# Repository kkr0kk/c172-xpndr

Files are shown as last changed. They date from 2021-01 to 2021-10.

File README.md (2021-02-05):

<H1>BENDIX king KT76C - flight sim transponder - for Cessna 172 - DIY</H1>
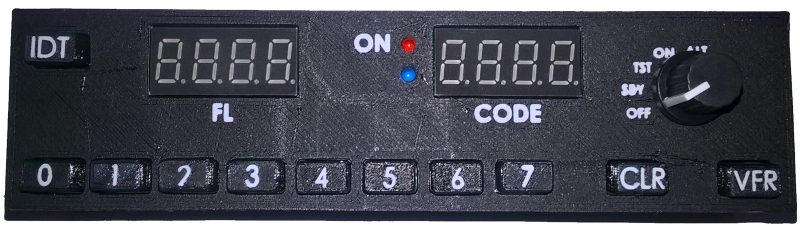
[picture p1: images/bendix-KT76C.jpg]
Bendix KT76C sim flight transponder

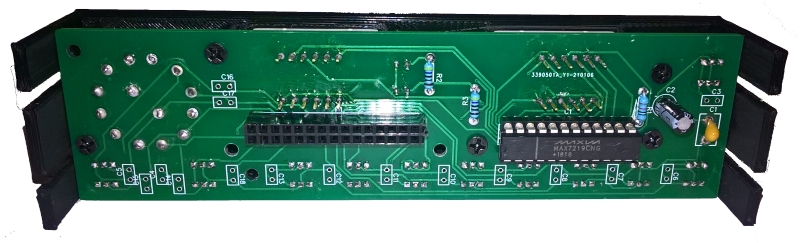
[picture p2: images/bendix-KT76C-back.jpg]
Bendix KT76C sim flight transponder

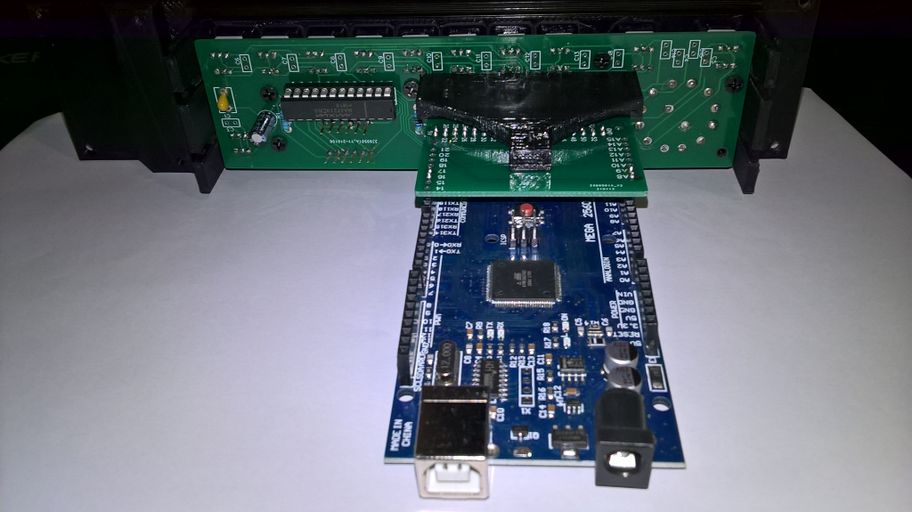
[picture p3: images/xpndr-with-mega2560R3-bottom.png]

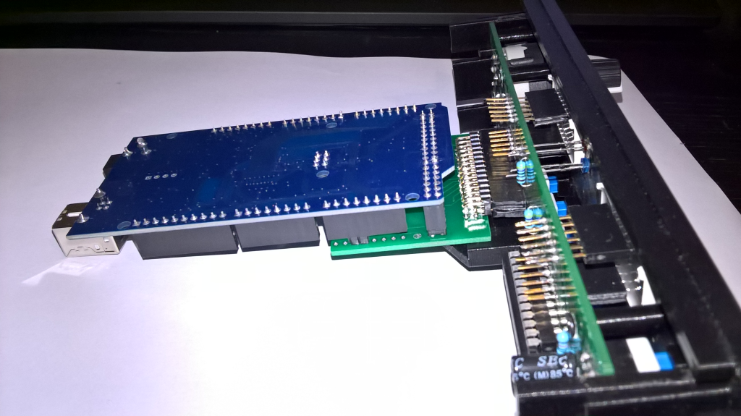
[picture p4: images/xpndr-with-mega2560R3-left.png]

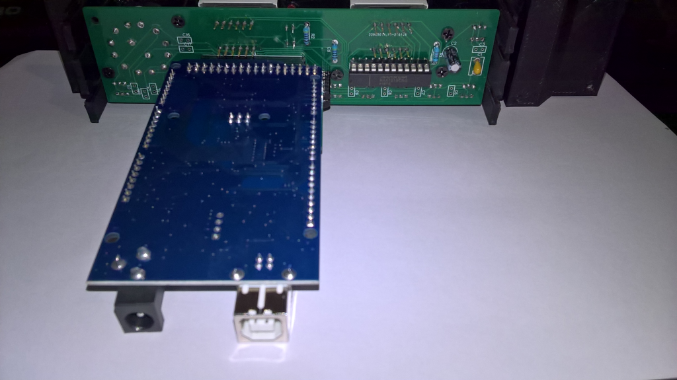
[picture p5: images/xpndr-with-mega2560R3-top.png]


Build your own transponder for simulation cockpit cessna 172.<BR />
Format for 6.25" stack<BR />
Electronics are design with EasyEDA.<BR />
3D parts are design with SolidWorks.<BR />
PCB are sold by JLCPCB, you can use directly Gerber files --> <a href='https://jlcpcb.com/'>JLCPCB</a><BR />
Only electronics, you can choose the microcontroller of your choice, the base design have addtionnal card for Mega2560R3.
For mine i use Mega2560R3 and Mobiflight on MSFS2020--> <a href='https://www.mobiflight.com/en/index.html'>MOBIFLIGHT</a><BR />
For others controllers you need to design the support for the card, or add wires to link them.
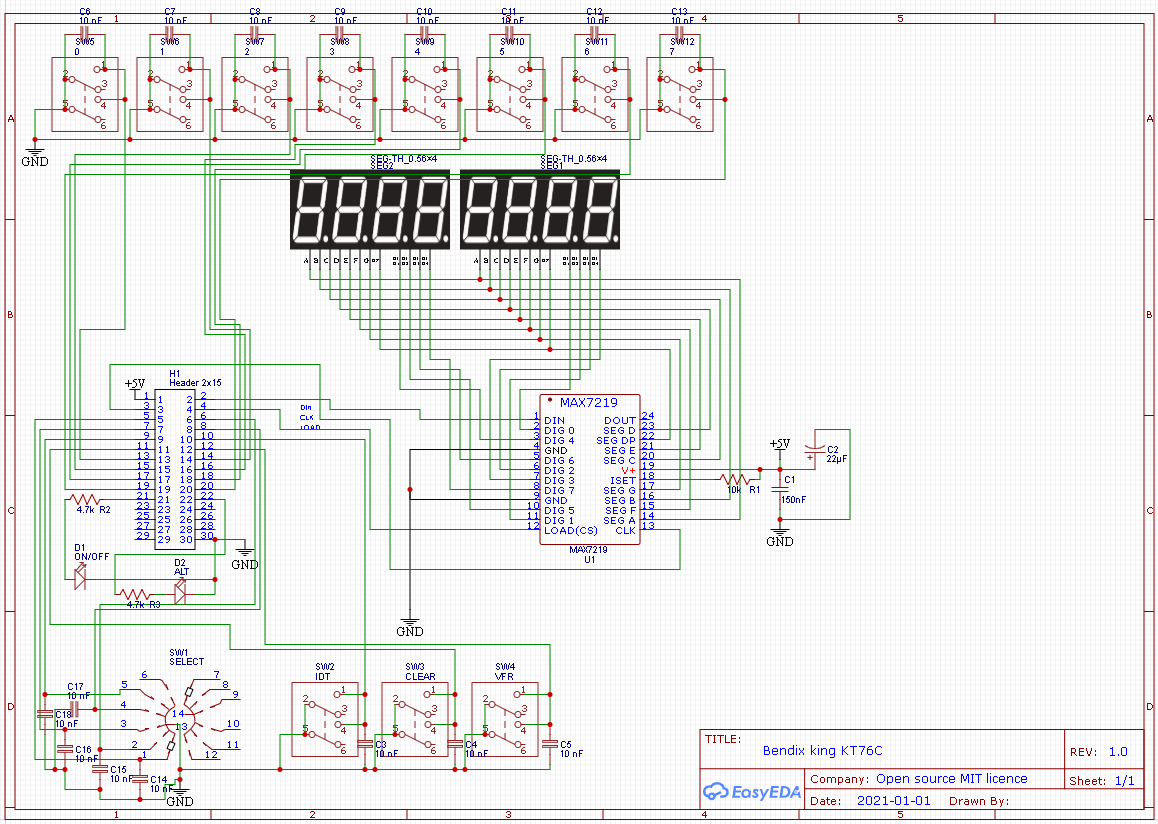
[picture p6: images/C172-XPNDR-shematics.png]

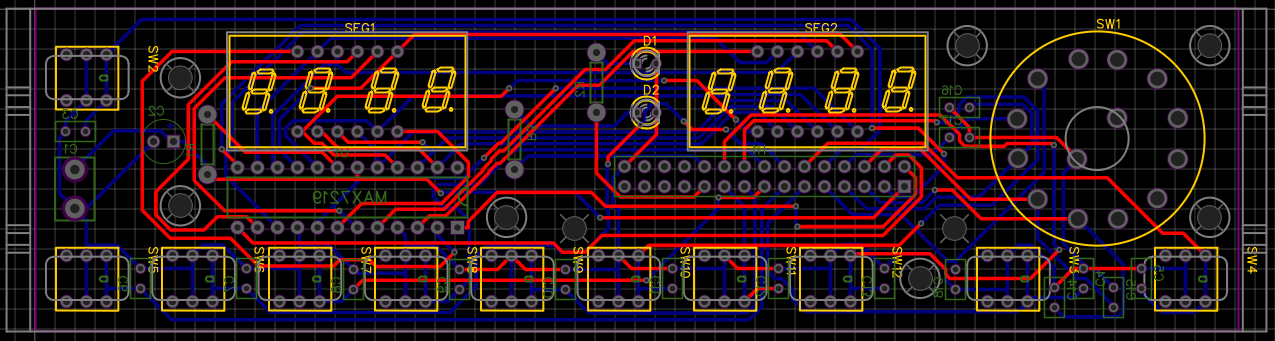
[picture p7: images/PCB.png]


Capacitor C3 to C18 are optionnals, they just do debounce for switch, but work fine wihtout on mobiflight.<BR/>

Parts list:

MAX7219 x1 --> <a href='https://fr.aliexpress.com/item/32874536319.html?spm=a2g0s.9042311.0.0.27426c37hpiJs6'>Aliexpress</a><BR />
Selector 2P6T x1 --> <a href='https://fr.aliexpress.com/item/32949497961.html?spm=a2g0s.9042311.0.0.338d6c379S0zX2'>Aliexpress</a><BR />
Screen 7 Seg 4 digits x2 --> <a href='https://fr.aliexpress.com/item/32673704841.html?spm=a2g0s.9042311.0.0.338d6c379S0zX2'>Aliexpress</a><BR />
Switch 8x8m x11 --> <a href='https://fr.aliexpress.com/item/32467872702.html?spm=a2g0s.9042311.0.0.338d6c379S0zX2'>Aliexpress</a><BR />
LED red 3mm x2 --> <a href='https://fr.aliexpress.com/item/4000968613440.html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,searchweb201602_,searchweb201603_'>Aliexpress</a><BR />
Capacitor 10nF x16--> <a href='https://fr.aliexpress.com/item/32971478818.html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,searchweb201602_,searchweb201603_'>Aliexpress</a>
<a href='https://fr.aliexpress.com/item/32896781515.html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,searchweb201602_,searchweb201603_'>Aliexpress</a><BR />
High Frequency Low ESR Aluminum Capacitor 22µF 50V x1 --> <a href='https://www.aliexpress.com/item/33030332216.html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,searchweb201602_,searchweb201603_'>Aliexpress</a><BR />
Capacitor 0.15µF x1 --> <a href='https://fr.aliexpress.com/item/32719073307.html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,searchweb201602_,searchweb201603_'>Aliexpress</a><BR />
Resistor 1/4W 10k&#x2126; x1<BR />
Resistor 1/4W 10k&#x2126; x2<BR />
Header male angle 2x15pin x1 --> <a href='https://fr.aliexpress.com/item/33043163402.html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,searchweb201602_,searchweb201603_'>Aliexpress</a><BR />
Header female 2x15pin x1<BR />
Header female 1x6pin x4 (for 7 segment) --> <a href='https://fr.aliexpress.com/item/4000106121057.html?spm=a2g0s.9042311.0.0.584d6c374vkTRE'>aliexpress</a><BR />

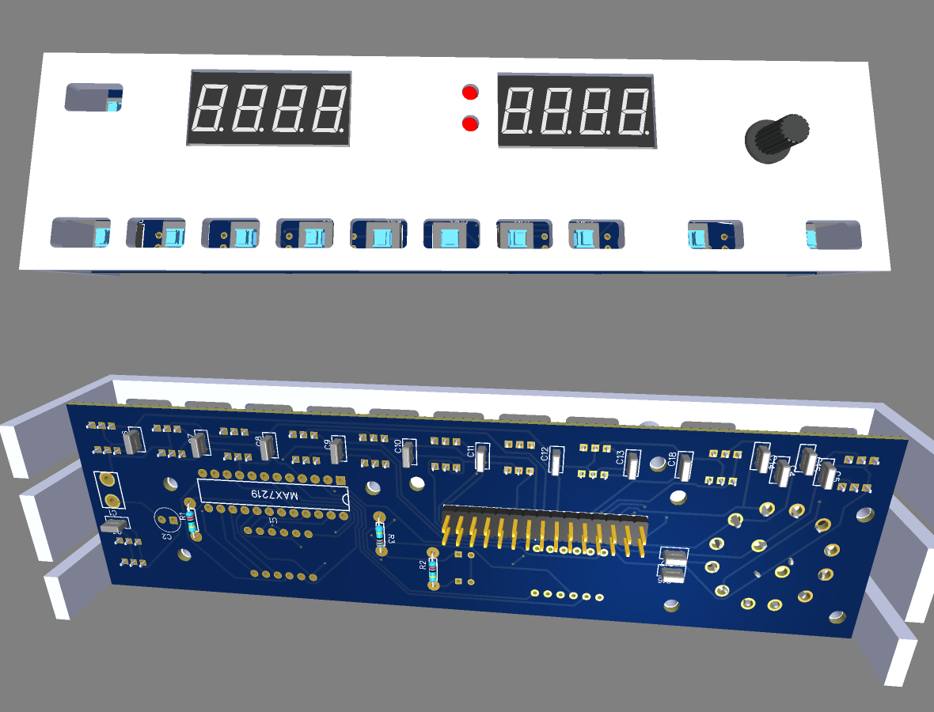
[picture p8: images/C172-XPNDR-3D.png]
<BR />
<table>
<tr>
	<th>PIN mega2560 R3</th><th>PIN Header H1</th><th>Device</th>
</tr>
<tr>
	<td>5V</td><td>1</td><td>--</td>
</tr><tr>
	<td>22</td><td>2</td><td>U1 - DIN (LCD)</td>
</tr><tr>
	<td>23</td><td>3</td><td>U1 - CLK (LCD)</td>
</tr><tr>
	<td>24</td><td>4</td><td>U1 - LOAD (LCD)</td>
</tr><tr>
	<td>25</td><td>5</td><td>SW1 - mode off</td>
</tr><tr>
	<td>26</td><td>6</td><td>SW1 - mode standby</td>
</tr><tr>
	<td>27</td><td>7</td><td>SW1 - mode test</td>
</tr><tr>
	<td>28</td><td>8</td><td>SW1 - mode on</td>
</tr><tr>
	<td>29</td><td>9</td><td>SW1 - mode alt</td>
</tr><tr>
	<td>30</td><td>10</td><td>SW2 - IDT</td>
</tr><tr>
	<td>31</td><td>11</td><td>SW3 - CLEAR</td>
</tr><tr>
	<td>32</td><td>12</td><td>SW4 - VFR</td>
</tr><tr>
	<td>33</td><td>13</td><td>SW5 - 0</td>
</tr><tr>
	<td>34</td><td>14</td><td>SW6 - 1</td>
</tr><tr>
	<td>35</td><td>15</td><td>SW6 - 2</td>
</tr><tr>
	<td>36</td><td>16</td><td>SW6 - 3</td>
</tr><tr>
	<td>37</td><td>17</td><td>SW6 - 4</td>
</tr><tr>
	<td>38</td><td>18</td><td>SW6 - 5</td>
</tr><tr>
	<td>39</td><td>19</td><td>SW6 - 6</td>
</tr><tr>
	<td>40</td><td>20</td><td>SW6 - 7</td>
</tr><tr>
	<td>41</td><td>21</td><td>LED D1 on/off</td>
</tr><tr>
	<td>42</td><td>22</td><td>LED D2 mode alt</td>
</tr><tr>
	<td>-</td><td>23</td><td>not use</td>
</tr><tr>
	<td>-</td><td>24</td><td>not use</td>
</tr><tr>
	<td>-</td><td>25</td><td>not use</td>
</tr><tr>
	<td>-</td><td>26</td><td>not use</td>
</tr><tr>
	<td>-</td><td>27</td><td>not use</td>
</tr><tr>
	<td>-</td><td>28</td><td>not use</td>
</tr><tr>
	<td>-</td><td>29</td><td>not use</td>
</tr><tr>
	<td>GND</td><td>30</td><td>GND</td>
</tr>
</table>
<H2>3D Printing</H2>
<H3>Materials</H3>
- HEAD : 0.2mm and 0.6mm<BR />
- PLA BLACK and PLA WHITE<BR />
<H3>How to print this with text</H3>
i use a rewrite plugin With CURA -> <a href='https://github.com/kkr0kk/c172-autopilot/blob/main/Gcode/pauseAtZ.py'>PauseAtZ</a><BR />
First you need to print just the text with head 0.2mm and white PLA (piece need to be rotate 180° text must be on the plate, keep your piece in center) -> <a href="https://github.com/kkr0kk/c172-xpndr/blob/main/STL%203Dprint%20files/chassis%20layer1.STL">STL file</a> or <a href="https://github.com/kkr0kk/c172-xpndr/blob/main/Gcode/chassis%20layer%201%20text%20head%200.2.gcode">GCODE file</a><BR />
When the text is print, Printer go pause, you can cancel the print.<BR />
Change the head by 0.6mm and load new PLA black (do enormous purge)<BR />
And go print the layer 2 -> <a href="https://github.com/kkr0kk/c172-xpndr/blob/main/STL%203Dprint%20files/chassis%20layer2.STL">STL file</a> or <a href="https://github.com/kkr0kk/c172-xpndr/blob/main/Gcode/chassis%20layer%202%20head%200.6.gcode">GCODE file</a><BR />
You can use cura profile -> <a href="https://github.com/kkr0kk/c172-xpndr/blob/main/Gcode/chassis%20text%20head%200.2%20layer%201.ini">Layer 1 profile with 0.2mm head</a> and <a href="https://github.com/kkr0kk/c172-xpndr/blob/main/Gcode/chassis%20layer%202%20head%200.6.gcode">layer 2 profile with 0.6mm head</a><BR />

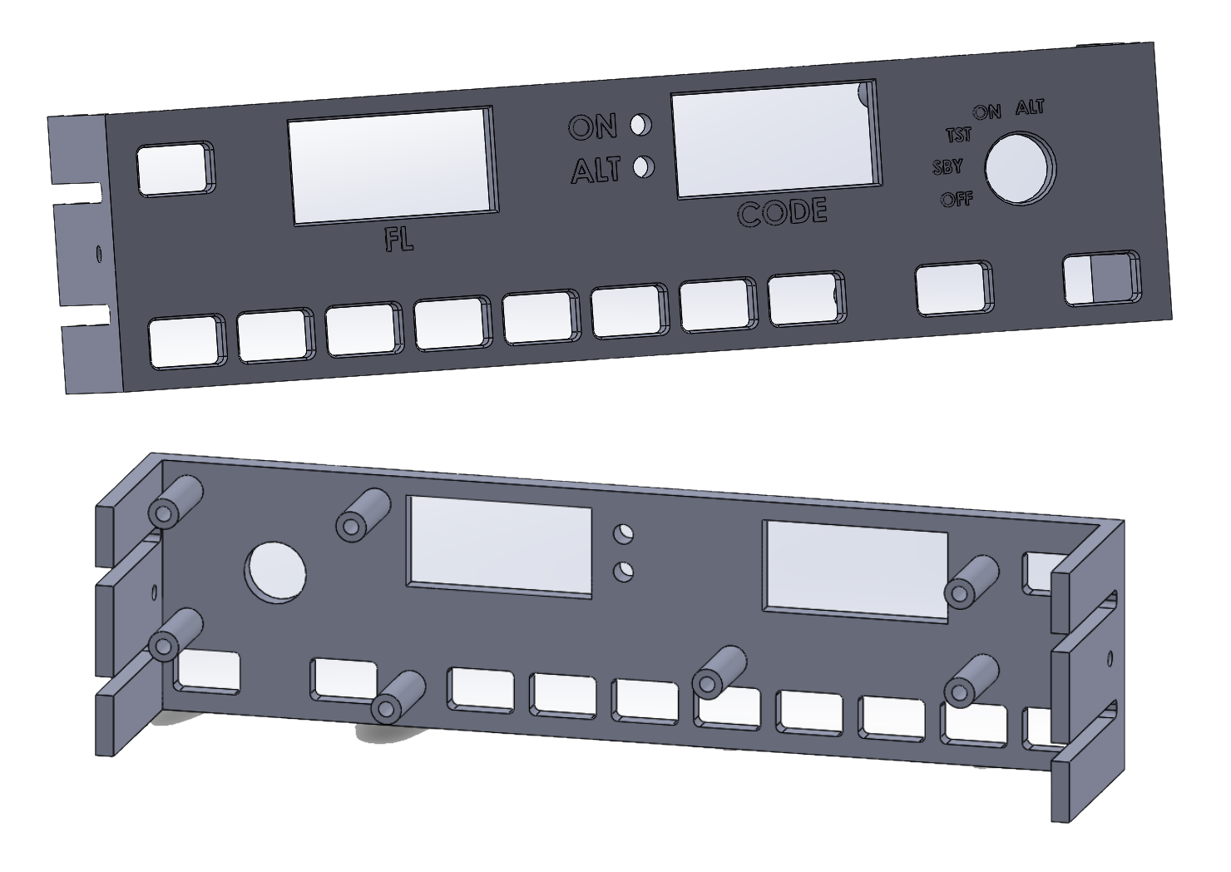
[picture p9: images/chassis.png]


<H2>SUPPORT for controller</H2>
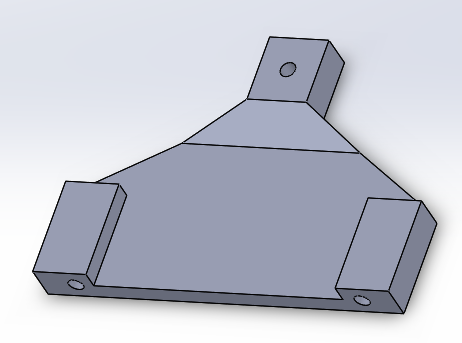
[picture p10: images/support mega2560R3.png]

<H3>Support for mega 2560 R3</H3>
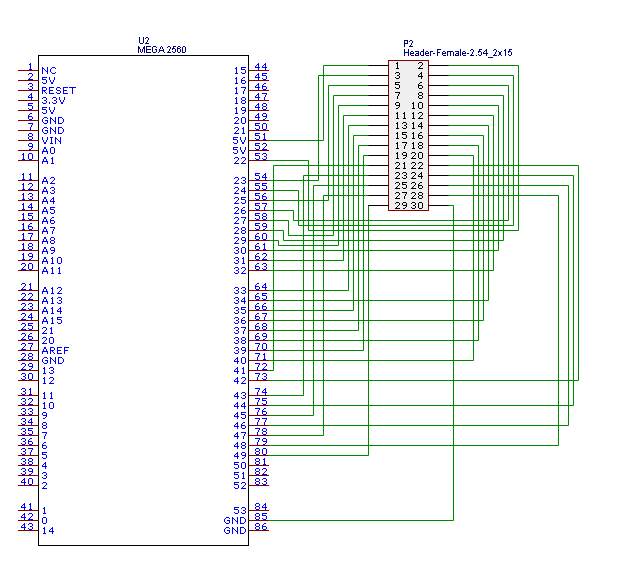
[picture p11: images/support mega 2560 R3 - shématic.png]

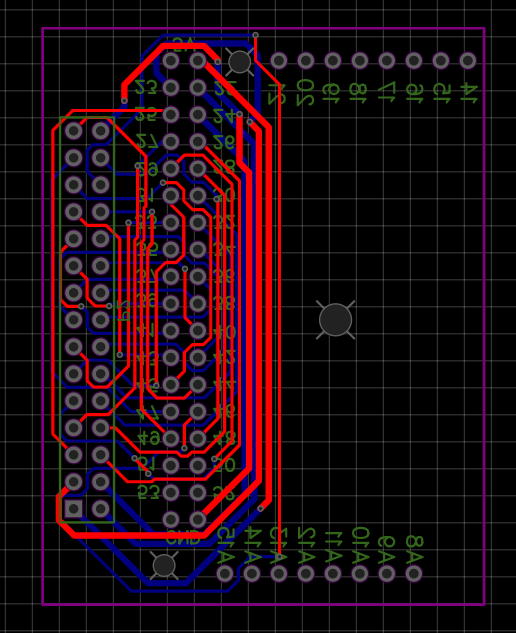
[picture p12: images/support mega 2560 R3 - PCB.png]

<H3>Support for mega 2560 pro mini</H3>
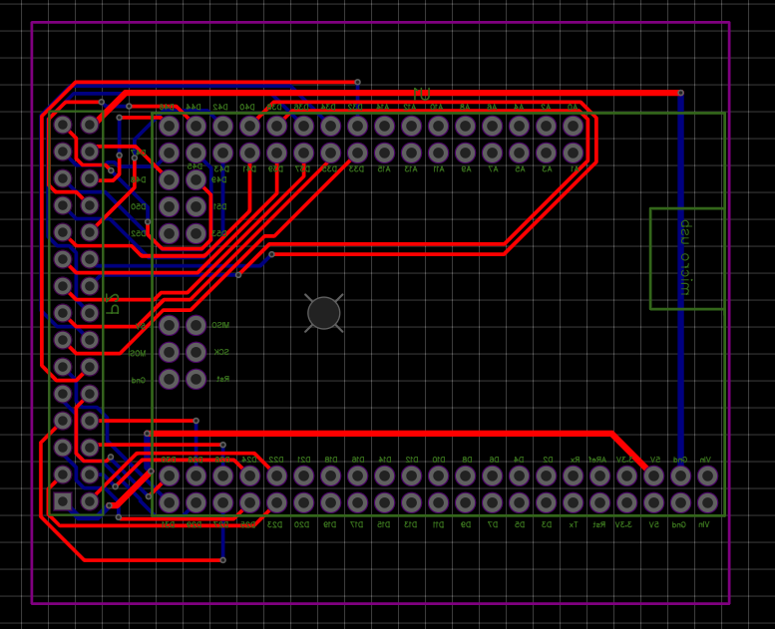
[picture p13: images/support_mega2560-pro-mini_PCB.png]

<H3>Adaptateur for 195x55 mm mount with front screws</H3>
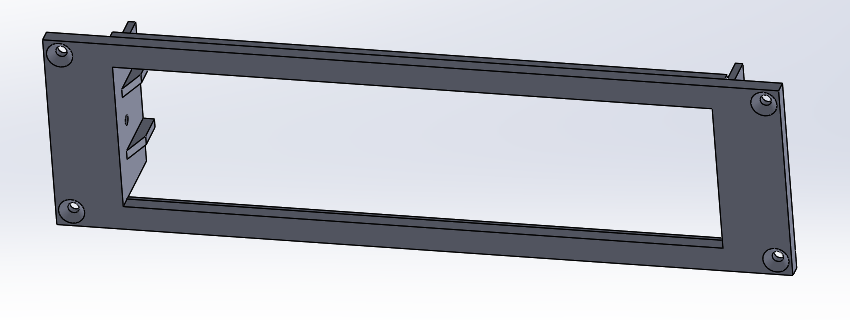
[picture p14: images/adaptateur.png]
<BR />
<H2>Other Projects</H2>
Build AutoPilot KAP140 for Cessna172 -> <a href='https://github.com/kkr0kk/c172-autopilot'>AutoPilot</a><BR />
Build GNS530 -> <a href='https://github.com/kkr0kk/GNS530'>GNS530</a><BR />

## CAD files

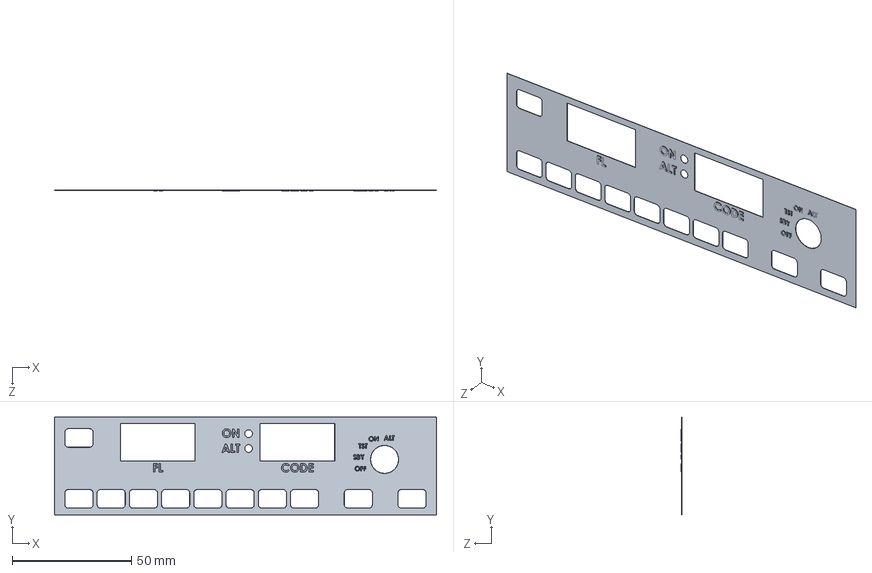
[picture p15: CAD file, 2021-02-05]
SolidWorks files/chassis layer1.SLDPRT
160.0 x 41.0 x 0.3 mm

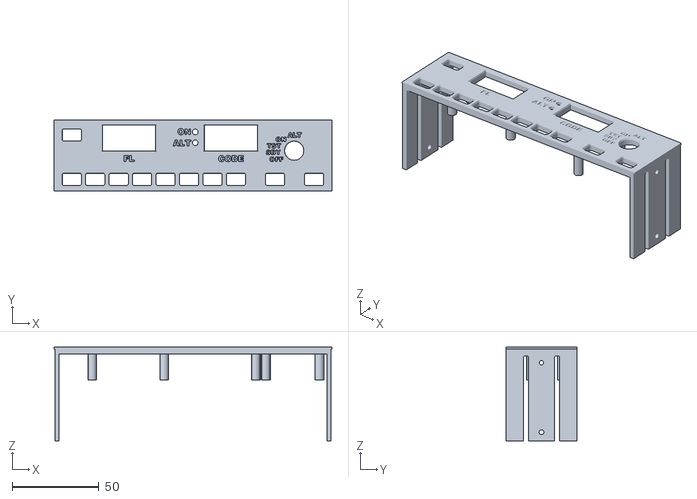
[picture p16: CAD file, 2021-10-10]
STL 3Dprint files/chassis with text high profundity.stl
160.0 x 41.0 x 54.0

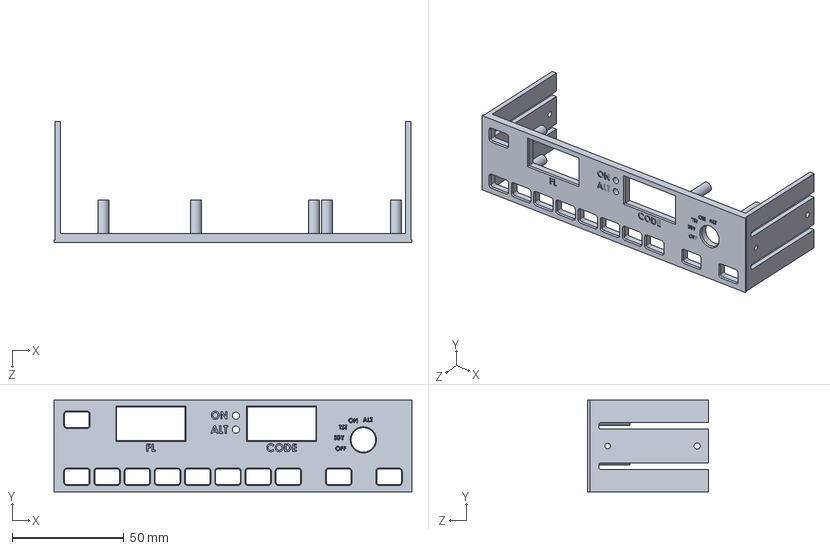
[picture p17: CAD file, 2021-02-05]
SolidWorks files/chassis layer2.SLDPRT
160.0 x 41.0 x 54.0 mm

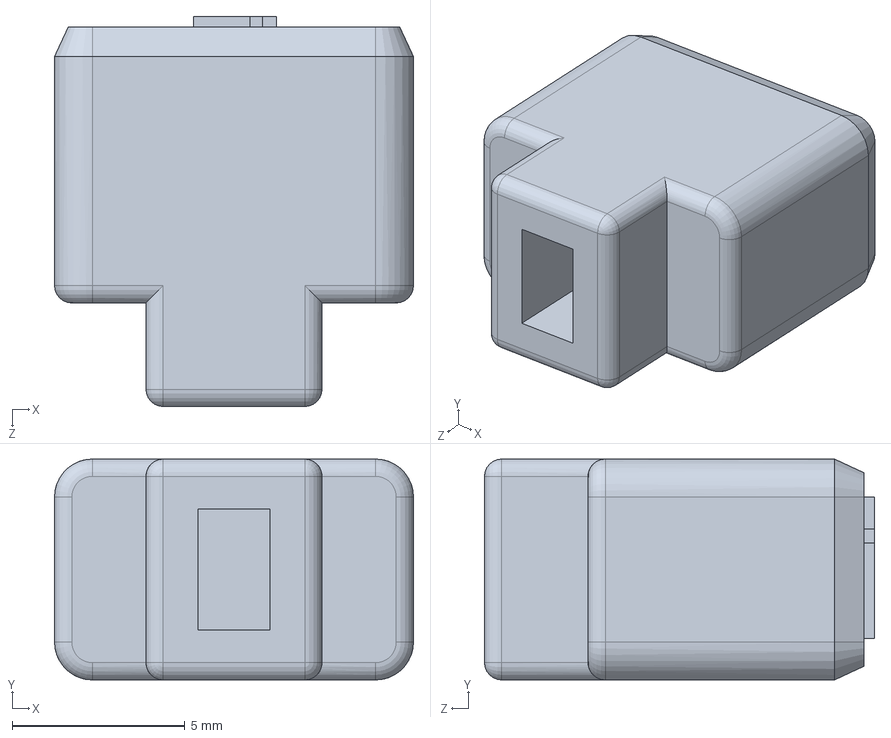
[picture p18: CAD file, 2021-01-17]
SolidWorks files/bouton-4.SLDPRT
10.4 x 6.40 x 11.3 mm

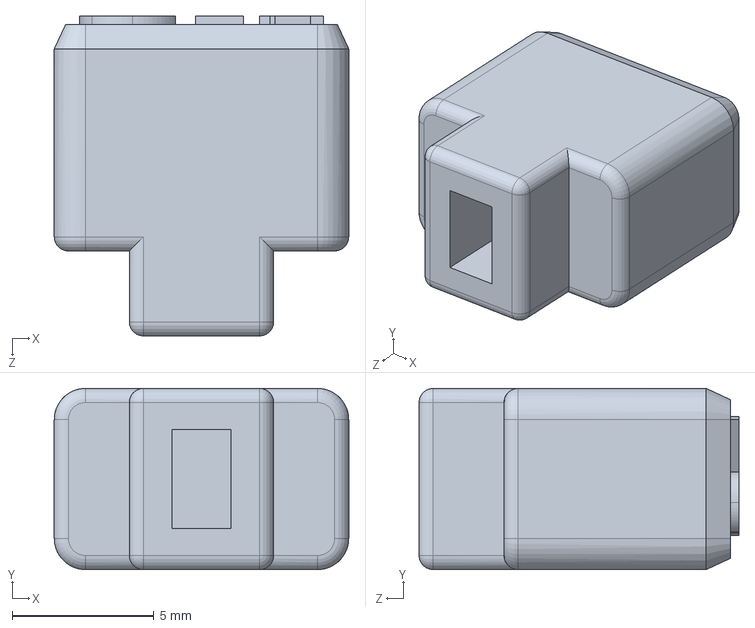
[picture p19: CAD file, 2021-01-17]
SolidWorks files/bouton-CLR.SLDPRT
10.4 x 6.40 x 11.3 mm

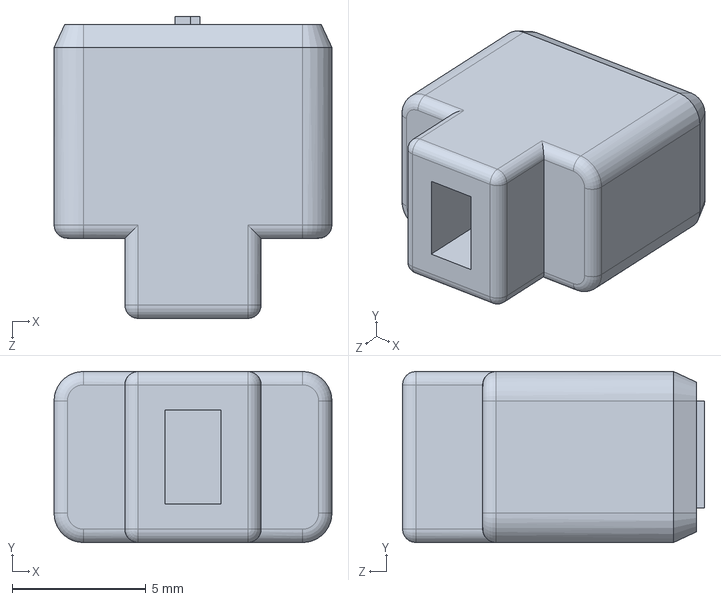
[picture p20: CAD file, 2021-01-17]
SolidWorks files/bouton-1.SLDPRT
10.4 x 6.40 x 11.3 mm

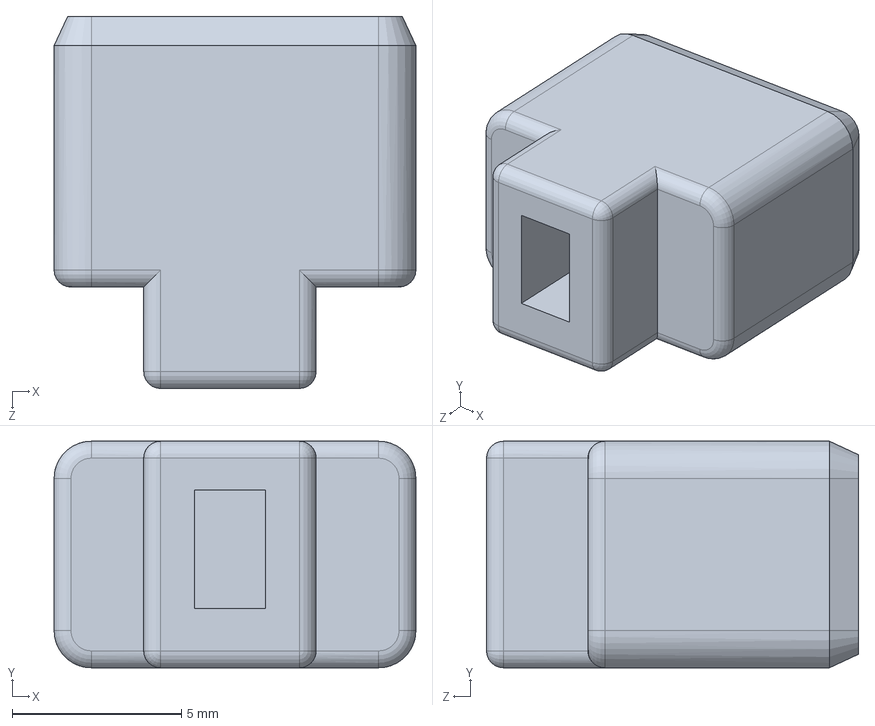
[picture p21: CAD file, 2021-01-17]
SolidWorks files/bouton.SLDPRT
10.7 x 6.70 x 11.0 mm

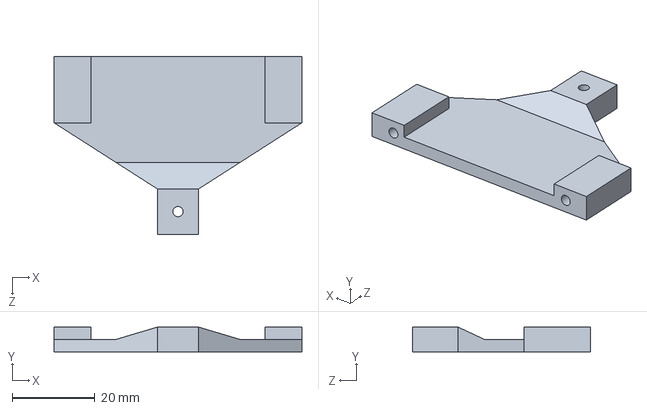
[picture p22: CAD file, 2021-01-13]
SolidWorks files/support - mega2560 pro mini.SLDPRT
60.0 x 6.00 x 43.0 mm

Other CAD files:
SolidWorks files/chassis.SLDPRT
SolidWorks files/chassis without text.SLDPRT
SolidWorks files/bouton-5.SLDPRT
SolidWorks files/bouton-IDT.SLDPRT
SolidWorks files/bouton-6.SLDPRT
SolidWorks files/bouton-3.SLDPRT
SolidWorks files/bouton-7.SLDPRT
SolidWorks files/bouton-VFR.SLDPRT
SolidWorks files/bouton-2.SLDPRT
SolidWorks files/bouton-0.SLDPRT
STL 3Dprint files/bouton-0.STL
STL 3Dprint files/bouton-1.STL
STL 3Dprint files/bouton-2.STL
STL 3Dprint files/bouton-3.STL
STL 3Dprint files/bouton-4.STL
STL 3Dprint files/bouton-5.STL
STL 3Dprint files/bouton-6.STL
STL 3Dprint files/bouton-7.STL
STL 3Dprint files/bouton-CLR.STL
STL 3Dprint files/bouton-IDT.STL
STL 3Dprint files/bouton-VFR.STL
STL 3Dprint files/bouton.STL
STL 3Dprint files/chassis layer1.STL
STL 3Dprint files/chassis layer2.STL
STL 3Dprint files/chassis without text.STL
STL 3Dprint files/chassis.STL
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

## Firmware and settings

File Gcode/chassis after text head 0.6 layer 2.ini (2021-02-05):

[profile]
layer_height = 0.3
wall_thickness = 1.2
retraction_enable = True
solid_layer_thickness = 1
fill_density = 30
print_speed = 60
print_temperature = 205
print_temperature2 = 193
print_temperature3 = 0
print_temperature4 = 0
print_temperature5 = 0
print_bed_temperature = 60
support = None
platform_adhesion = None
support_dual_extrusion = Both
wipe_tower = False
wipe_tower_volume = 15
ooze_shield = False
filament_diameter = 1.75
filament_diameter2 = 1.75
filament_diameter3 = 0
filament_diameter4 = 0
filament_diameter5 = 0
filament_flow = 100
nozzle_size = 0.6
retraction_speed = 60
retraction_amount = 5
retraction_dual_amount = 16.5
retraction_min_travel = 0.1
retraction_combing = All
retraction_minimal_extrusion = 0
retraction_hop = 0.5
bottom_thickness = 0.20
layer0_width_factor = 100
object_sink = 0.0
overlap_dual = 0.15
travel_speed = 60
bottom_layer_speed = 40
infill_speed = 60
solidarea_speed = 60
inset0_speed = 40
insetx_speed = 60
cool_min_layer_time = 10
fan_enabled = True
skirt_line_count = 0
skirt_gap = 0
skirt_minimal_length = 0
fan_full_height = 0.75
fan_speed = 20
fan_speed_max = 40
cool_min_feedrate = 10
cool_head_lift = False
solid_top = True
solid_bottom = True
fill_overlap = 0
perimeter_before_infill = True
support_type = Lines
support_angle = 45
support_fill_rate = 18
support_xy_distance = 0.8
support_z_distance = 0.25
spiralize = False
simple_mode = False
brim_line_count = 6
raft_margin = 5.0
raft_line_spacing = 3.0
raft_base_thickness = 0.3
raft_base_linewidth = 1.0
raft_interface_thickness = 0.27
raft_interface_linewidth = 0.4
raft_airgap_all = 0.0
raft_airgap = 0.22
raft_surface_layers = 2
raft_surface_thickness = 0.27
raft_surface_linewidth = 0.4
fix_horrible_union_all_type_a = True
fix_horrible_union_all_type_b = False
fix_horrible_use_open_bits = False
fix_horrible_extensive_stitching = False
plugin_config = (lp1
	.
object_center_x = -1
object_center_y = -1

[alterations]
start.gcode = ;Sliced at: {day} {date} {time}
	;Basic settings: Layer height: {layer_height} Walls: {wall_thickness} Fill: {fill_density}
	;Print time: {print_time}
	;Filament used: {filament_amount}m {filament_weight}g
	;Filament cost: {filament_cost}
	;M190 S{print_bed_temperature} ;Uncomment to add your own bed temperature line
	;M109 S{print_temperature} ;Uncomment to add your own temperature line
	G21        ;metric values
	G90        ;absolute positioning
	M82        ;set extruder to absolute mode
	M107       ;start with the fan off
	G28 X0 Y0  ;move X/Y to min endstops
	G28 Z0     ;move Z to min endstops
	G1 Z15.0 F{travel_speed} ;move the platform down 15mm
	G92 E0                  ;zero the extruded length
	G1 F200 E3              ;extrude 3mm of feed stock
	G92 E0                  ;zero the extruded length again
	G1 F{travel_speed}
	;Put printing message on LCD screen
	M117 Printing...
end.gcode = ;End GCode
	M104 S0                     ;extruder heater off
	M140 S0                     ;heated bed heater off (if you have it)
	G91                                    ;relative positioning
	G1 E-1 F300                            ;retract the filament a bit before lifting the nozzle, to release some of the pressure
	G1 Z+0.5 E-5 X-20 Y-20 F{travel_speed} ;move Z up a bit and retract filament even more
	G28 X0 Y0                              ;move X/Y to min endstops, so the head is out of the way
	M84                         ;steppers off
	G90                         ;absolute positioning
	;{profile_string}
start2.gcode = ;Sliced at: {day} {date} {time}
	;Basic settings: Layer height: {layer_height} Walls: {wall_thickness} Fill: {fill_density}
	;Print time: {print_time}
	;Filament used: {filament_amount}m {filament_weight}g
	;Filament cost: {filament_cost}
	;M190 S{print_bed_temperature} ;Uncomment to add your own bed temperature line
	;M104 S{print_temperature} ;Uncomment to add your own temperature line
	;M109 T1 S{print_temperature2} ;Uncomment to add your own temperature line
	;M109 T0 S{print_temperature} ;Uncomment to add your own temperature line
	G21        ;metric values
	G90        ;absolute positioning
	M107       ;start with the fan off
	G28 X0 Y0  ;move X/Y to min endstops
	G28 Z0     ;move Z to min endstops
	G1 Z15.0 F{travel_speed} ;move the platform down 15mm
	T1                      ;Switch to the 2nd extruder
	G92 E0                  ;zero the extruded length
	G1 F200 E10             ;extrude 10mm of feed stock
	G92 E0                  ;zero the extruded length again
	G1 F200 E-{retraction_dual_amount}
	T0                      ;Switch to the first extruder
	G92 E0                  ;zero the extruded length
	G1 F200 E10             ;extrude 10mm of feed stock
	G92 E0                  ;zero the extruded length again
	G1 F{travel_speed}
	;Put printing message on LCD screen
	M117 Printing...
end2.gcode = ;End GCode
	M104 T0 S0                     ;extruder heater off
	M104 T1 S0                     ;extruder heater off
	M140 S0                     ;heated bed heater off (if you have it)
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
